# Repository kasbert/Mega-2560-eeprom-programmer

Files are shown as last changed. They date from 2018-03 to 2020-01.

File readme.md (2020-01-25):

# EEprom programmer with Mega 2560

Links:
http://danceswithferrets.org/geekblog/?page_id=903

http://danceswithferrets.org/geekblog/?p=496

Just upload sketch into Mega 2560 arduino.
Build and attach adapter (LED's + resistors are optional):

PCB Eagle+Gerber (Elecrow/Jlcpcb) are in pcb:

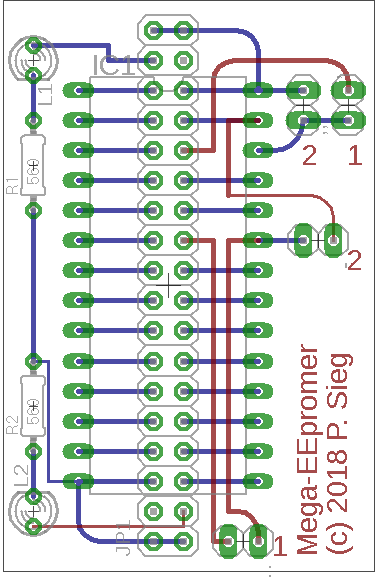
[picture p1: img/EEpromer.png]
PCB


2 Jumper at 1 are for 28C256 and 28C64.
2 Jumper at 2 are for 28C16.

PCB's arrived and they work as expected.

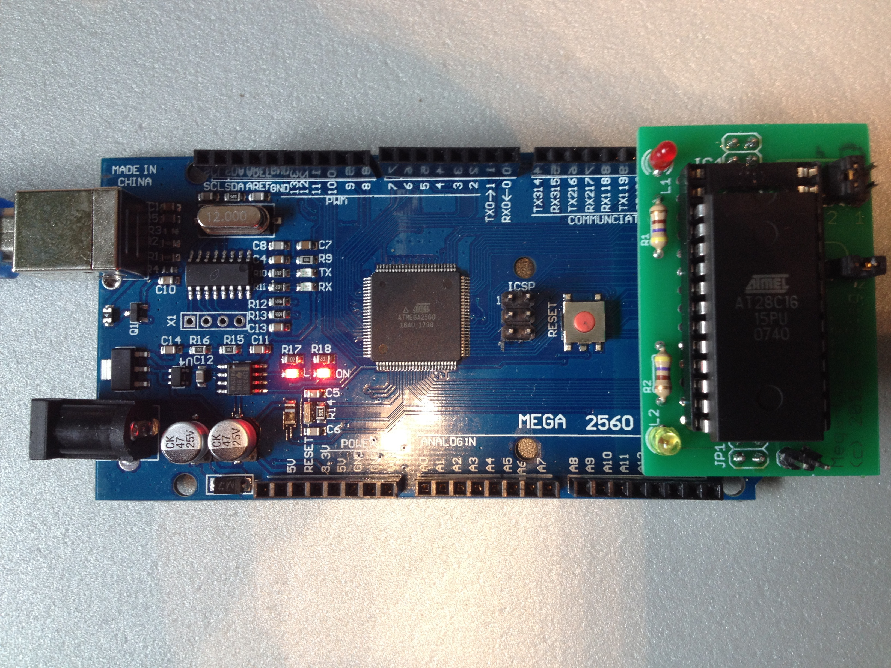
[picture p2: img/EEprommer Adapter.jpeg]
JCLPCB


See eeprom.ino and eeprommer.py for details

---
Hardware variant 2 uses Mega 2560 Pro Mini and the long side of pins.

Atmega 2560 Pins 31 - 4 are connected to EEPROM
```
 D4---A14 -+---+- VCC---5V
 D6---A12 -+ E +- /WE---D7
 D8----A7 -+ E +- A13---D9
D10----A6 -+ P +- A8----D11
D12----A5 -+ R +- A9 ---D13
D14----A4 -+ O +- A11---D15
D16----A3 -+ M +- /OE---D17
D18----A2 -+   +- A10---D19
D20----A1 -+   +- /CE---D21
D22----A0 -+   +- D7----D23
D24----D0 -+   +- D6----D25
D26----D1 -+   +- D5----D27
D28----D2 -+   +- D4----D29
GND---GND -+---+- D3----D31
```
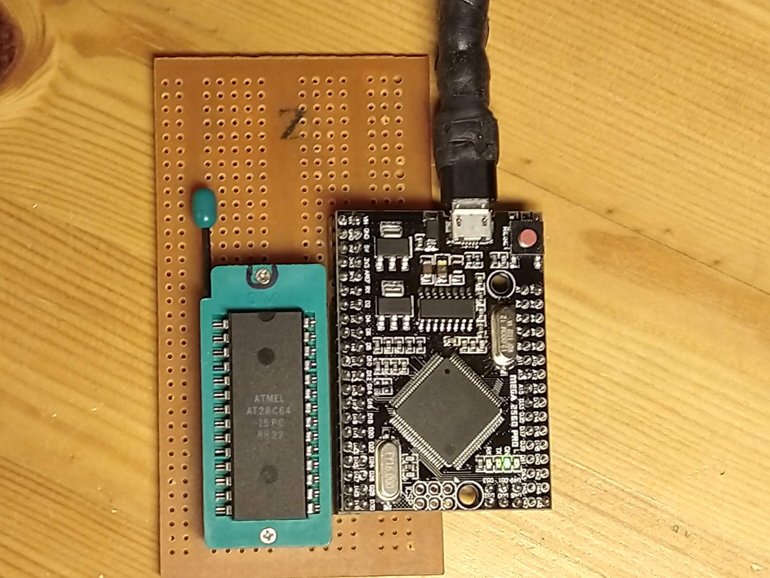
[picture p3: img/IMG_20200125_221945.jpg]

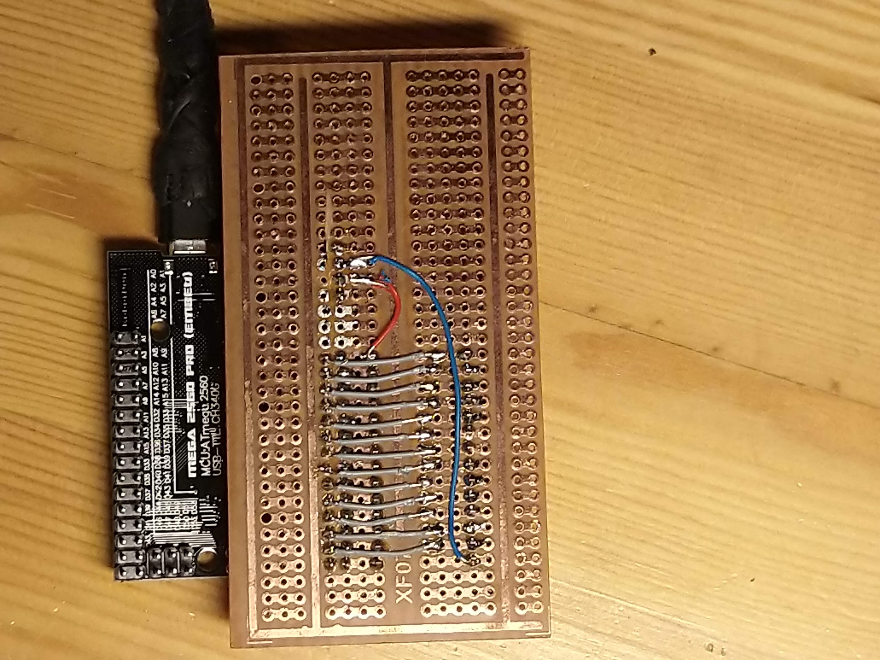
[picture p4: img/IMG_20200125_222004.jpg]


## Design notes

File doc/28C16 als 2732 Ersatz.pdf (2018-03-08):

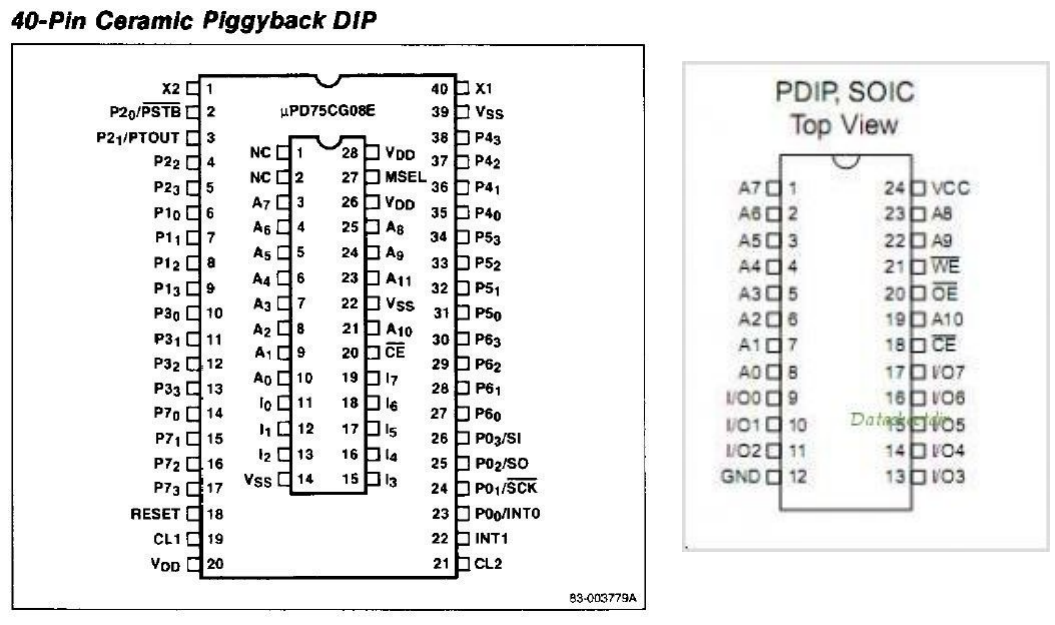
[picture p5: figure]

AT28C16 anstatt 2732 nehmen beim uPD75CG08

Pin 21-/WE aus der Fassung lassen (braucht nicht mit VCC/VDD=+5V verbunden werden). Der wäre sonst mit A11 verbunden, was wir nicht wollen.
/OE liegt an VSS=GND – das sollte so passen
Die anderen Pins passen übereinander

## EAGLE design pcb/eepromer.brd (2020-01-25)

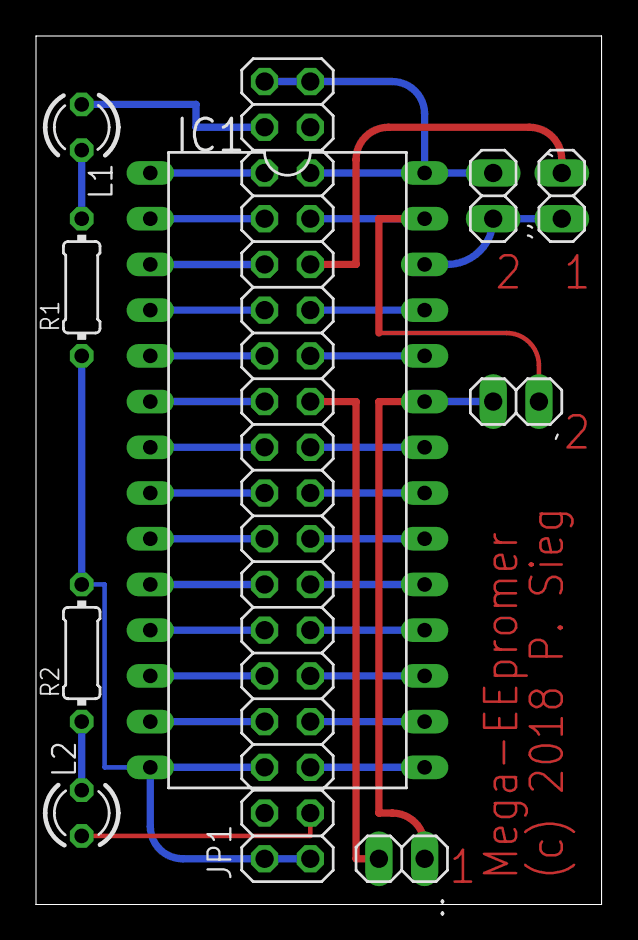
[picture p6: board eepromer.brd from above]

Board: 2 copper layers, 31.4 x 48.2 mm, 10 parts (0 on the bottom side), 34 nets.

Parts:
': 1X02
,: 1X02
,,: 1X02
:: 1X02
IC1: DIL28-6
JP1: 2X18
L1, L2: LED3MM
R1, R2: 560; 0204/7

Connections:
S$1: ,.1, IC1.28, JP1.31, JP1.36
S$2: IC1.14, JP1.1, JP1.6, R1.1, R2.2
S$3: JP1.3, L2.A
S$4: ,,.2, JP1.27
S$5: ,.2, ,,.1, IC1.26
S$6: L2.K, R2.1
S$7: '.1, IC1.27, JP1.29
S$8: IC1.25, JP1.25
S$9: IC1.24, JP1.23
S$10: IC1.22, JP1.19
S$11: IC1.21, JP1.17
S$12: IC1.20, JP1.15
S$13: IC1.19, JP1.13
S$14: IC1.18, JP1.11
S$15: IC1.17, JP1.9
S$16: IC1.16, JP1.7
S$17: IC1.15, JP1.5
S$18: IC1.13, JP1.8
S$19: IC1.12, JP1.10
S$20: IC1.11, JP1.12
S$21: IC1.10, JP1.14
S$22: IC1.9, JP1.16
S$23: IC1.8, JP1.18
S$24: IC1.7, JP1.20
S$25: IC1.6, JP1.22
S$26: IC1.5, JP1.24
S$27: IC1.4, JP1.26
S$28: IC1.3, JP1.28
S$29: IC1.2, JP1.30
S$30: IC1.1, JP1.32
S$31: :.2, JP1.21
S$32: '.2, :.1, IC1.23
S$33: L1.K, R1.2
S$34: JP1.34, L1.A

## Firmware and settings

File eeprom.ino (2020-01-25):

// EEPROM Programmer - code for an Arduino Mega 2560
//
// Written by K Adcock.
//       Jan 2016 - Initial release
//       Dec 2017 - Slide code tartups, to remove compiler errors for new Arduino IDE (1.8.5).
//   7th Dec 2017 - Updates from Dave Curran of Tynemouth Software, adding commands to enable/disable SDP.
//  10th Dec 2017 - Fixed one-byte EEPROM corruption (always byte 0) when unprotecting an EEPROM
//                  (doesn't matter if you write a ROM immediately after, but does matter if you use -unprotect in isolation)
//                - refactored code a bit (split loop() into different functions)
//                - properly looked at timings on the Atmel datasheet, and worked out that my delays
//                  during reads and writes were about 10,000 times too big!
//                  Reading and writing is now orders-of-magnitude quicker.
//  21st Feb 2018 - P. Sieg
//                  static const long int k_uTime_WriteDelay_uS = 500; // delay between byte writes - needed for at28c16
//                  delayMicroseconds(k_uTime_WritePulse_uS);
//  06th Oct 2018 - P. Sieg
//                - corrected SDP (un)protect adresses & k_uTime_WriteDelay_uS
//                - Set parameters -A=28C16; -B=28C64; -C=28C256
//  29th Jan 2019 - P. Sieg
//                - Introduced + and - to alter k_uTime_WritePulse_uS
//  25th Jan 2020 - J. Sonninen
//                - Add read polling after write
//
//
// Distributed under an acknowledgement licence, because I'm a shallow, attention-seeking tart. :)
//
// http://danceswithferrets.org/geekblog/?page_id=903
//
// This software presents a 9600-8N1 serial port.
//
// R[hex address]                         - reads 16 bytes of data from the EEPROM
// W[hex address]:[data in two-char hex]  - writes up to 16 bytes of data to the EEPROM
// P                                      - set write-protection bit (Atmels only, AFAIK)
// U                                      - clear write-protection bit (ditto)
// V                                      - prints the version string
// A                                      - set parameters for 28C16
// B                                      - set parameters for 28C64
// C                                      - set parameters for 28C256
// +                                      - k_uTime_WritePulse_uS + 50
// -                                      - k_uTime_WritePulse_uS - 25
//
// Any data read from the EEPROM will have a CRC checksum appended to it (separated by a comma).
// If a string of data is sent with an optional checksum, then this will be checked
// before anything is written.
//

#include <avr/pgmspace.h>

const char hex[] =
{
  '0', '1', '2', '3', '4', '5', '6', '7',
  '8', '9', 'a', 'b', 'c', 'd', 'e', 'f'
};

const char version_string[] = {"EEPROM Version=0.05-kasbert"};

#define HW_VARIANT 0 // Select 1 or 2

#if HW_VARIANT == 1
static const int kPin_Addr14  = 24;
static const int kPin_Addr12  = 26;
static const int kPin_Addr7   = 28;
static const int kPin_Addr6   = 30;
static const int kPin_Addr5   = 32;
static const int kPin_Addr4   = 34;
static const int kPin_Addr3   = 36;
static const int kPin_Addr2   = 38;
static const int kPin_Addr1   = 40;
static const int kPin_Addr0   = 42;
static const int kPin_Data0   = 44;
static const int kPin_Data1   = 46;
static const int kPin_Data2   = 48;
static const int kPin_nWE     = 27;
static const int kPin_Addr13  = 29;
static const int kPin_Addr8   = 31;
static const int kPin_Addr9   = 33;
static const int kPin_Addr11  = 35;
static const int kPin_nOE     = 37;
static const int kPin_Addr10  = 39;
static const int kPin_nCE     = 41;
static const int kPin_Data7   = 43;
static const int kPin_Data6   = 45;
static const int kPin_Data5   = 47;
static const int kPin_Data4   = 49;
static const int kPin_Data3   = 51;
static const int kPin_WaitingForInput  = 13;
static const int kPin_LED_Red = 22;
static const int kPin_LED_Grn = 53;
#elif HW_VARIANT == 2
static const int kPin_Addr14  = 4;
static const int kPin_Addr12  = 6;
static const int kPin_Addr7   = 8;
static const int kPin_Addr6   = 10;
static const int kPin_Addr5   = 12;
static const int kPin_Addr4   = 14;
static const int kPin_Addr3   = 16;
static const int kPin_Addr2   = 18;
static const int kPin_Addr1   = 20;
static const int kPin_Addr0   = 22;
static const int kPin_Data0   = 24;
static const int kPin_Data1   = 26;
static const int kPin_Data2   = 28;
static const int kPin_nWE     = 7;
static const int kPin_Addr13  = 9;
static const int kPin_Addr8   = 11;
static const int kPin_Addr9   = 13;
static const int kPin_Addr11  = 15;
static const int kPin_nOE     = 17;
static const int kPin_Addr10  = 19;
static const int kPin_nCE     = 21;
static const int kPin_Data7   = 23;
static const int kPin_Data6   = 25;
static const int kPin_Data5   = 27;
static const int kPin_Data4   = 29;
static const int kPin_Data3   = 31;
static const int kPin_WaitingForInput  = 48;
static const int kPin_LED_Red = 50;
static const int kPin_LED_Grn = 52;
#else
#error Select HW_VARIANT 1 or 2
#endif


byte g_cmd[80]; // strings received from the controller will go in here
static const int kMaxBufferSize = 16;
byte buffer[kMaxBufferSize];

static const long int k_uTime_WritePulse_uS = 1; 
static const long int k_uTime_ReadPulse_uS = 1;
             long int k_uTime_WriteDelay_uS = -1; // delay between byte writes - needed for at28c16
// (to be honest, both of the above are about ten times too big - but the Arduino won't reliably
// delay down at the nanosecond level, so this is the best we can do.)
// -1 enables polling of written value. At least 28C64 reads inverted value until the write has completed.
             long int SDPadr1=0x5555, SDPadr2=0x2AAA; // default 28C256
// the setup function runs once when you press reset or power the board
void setup()
{
  Serial.begin(9600);
//  Serial.println(version_string);
  
  pinMode(kPin_WaitingForInput, OUTPUT); digitalWrite(kPin_WaitingForInput, HIGH);
  pinMode(kPin_LED_Red, OUTPUT); digitalWrite(kPin_LED_Red, LOW);
  pinMode(kPin_LED_Grn, OUTPUT); digitalWrite(kPin_LED_Grn, LOW);

  // address lines are ALWAYS outputs
  pinMode(kPin_Addr0,  OUTPUT);
  pinMode(kPin_Addr1,  OUTPUT);
  pinMode(kPin_Addr2,  OUTPUT);
  pinMode(kPin_Addr3,  OUTPUT);
  pinMode(kPin_Addr4,  OUTPUT);
  pinMode(kPin_Addr5,  OUTPUT);
  pinMode(kPin_Addr6,  OUTPUT);
  pinMode(kPin_Addr7,  OUTPUT);
  pinMode(kPin_Addr8,  OUTPUT);
  pinMode(kPin_Addr9,  OUTPUT);
  pinMode(kPin_Addr10, OUTPUT);
  pinMode(kPin_Addr11, OUTPUT);
  pinMode(kPin_Addr12, OUTPUT);
  pinMode(kPin_Addr13, OUTPUT);
  pinMode(kPin_Addr14, OUTPUT);

  // control lines are ALWAYS outputs
  pinMode(kPin_nCE, OUTPUT); digitalWrite(kPin_nCE, LOW); // might as well keep the chip enabled ALL the time
  pinMode(kPin_nOE, OUTPUT); digitalWrite(kPin_nOE, HIGH);
  pinMode(kPin_nWE, OUTPUT); digitalWrite(kPin_nWE, HIGH); // not writing

  SetDataLinesAsInputs();
  SetAddress(0);
}

void loop()
{
  while (true)
  {
    digitalWrite(kPin_WaitingForInput, HIGH);
    ReadString();
    digitalWrite(kPin_WaitingForInput, LOW);
    
    switch (g_cmd[0])
    {
      case 'V': Serial.println(version_string); break;
      case 'P': SetSDPState(true); break;
      case 'U': SetSDPState(false); break;
      case 'R': ReadEEPROM(); break;
      case 'W': WriteEEPROM(); break;
      case 'A': k_uTime_WriteDelay_uS=100;  
                SDPadr1=-1; SDPadr2=-1; Serial.println("Set params for 28C16");break;
      case 'B': k_uTime_WriteDelay_uS=5;  
                SDPadr1=0x1555; SDPadr2=0x0AAA; Serial.println("Set params for 28C64");break;
      case 'C': k_uTime_WriteDelay_uS=5;  
                SDPadr1=0x5555; SDPadr2=0x2AAA; Serial.println("Set params for 28C256");break;
      case 'D': k_uTime_WriteDelay_uS=-1;  
                Serial.println("Poll read after write");break;
      case '+': k_uTime_WriteDelay_uS=k_uTime_WriteDelay_uS+50;  
                if (k_uTime_WriteDelay_uS > 500) k_uTime_WriteDelay_uS = 500; 
                Serial.print("k_uTime_WriteDelay_uS=");Serial.println(k_uTime_WriteDelay_uS,DEC); break;
      case '-': k_uTime_WriteDelay_uS=k_uTime_WriteDelay_uS-25; 
                if (k_uTime_WriteDelay_uS < 5) k_uTime_WriteDelay_uS = 5; 
                Serial.print("k_uTime_WriteDelay_uS=");Serial.println(k_uTime_WriteDelay_uS,DEC); break;
      case 0: break; // empty string. Don't mind ignoring this.
      default: Serial.println("ERR Unrecognised command"); break;
    }
  }
}

void ReadEEPROM() // R<address>  - read kMaxBufferSize bytes from EEPROM, beginning at <address> (in hex)
{
  if (g_cmd[1] == 0)
  {
    Serial.println("ERR");
    return;
  }

  // decode ASCII representation of address (in hex) into an actual value
  int addr = 0;
  int x = 1;
  while (x < 5 && g_cmd[x] != 0)
  {
    addr = addr << 4;
    addr |= HexToVal(g_cmd[x++]);
  }     

  digitalWrite(kPin_nWE, HIGH); // disables write
  SetDataLinesAsInputs();
  digitalWrite(kPin_nOE, LOW); // makes the EEPROM output the byte
  delayMicroseconds(1);
      
  ReadEEPROMIntoBuffer(addr, kMaxBufferSize);

  // now print the results, starting with the address as hex ...
  Serial.print(hex[ (addr & 0xF000) >> 12 ]);
  Serial.print(hex[ (addr & 0x0F00) >> 8  ]);
  Serial.print(hex[ (addr & 0x00F0) >> 4  ]);
  Serial.print(hex[ (addr & 0x000F)       ]);
  Serial.print(":");
  PrintBuffer(kMaxBufferSize);

  Serial.println("OK");

  digitalWrite(kPin_nOE, HIGH); // stops the EEPROM outputting the byte
}

void WriteEEPROM() // W<four byte hex address>:<data in hex, two characters per byte, max of 16 bytes per line>
{
  if (g_cmd[1] == 0)
  {
    Serial.println("ERR");
    return;
  }

  int addr = 0;
  int x = 1;
  while (g_cmd[x] != ':' && g_cmd[x] != 0)
  {
    addr = addr << 4;
    addr |= HexToVal(g_cmd[x]);
    ++x;
  }

  // g_cmd[x] should now be a :
  if (g_cmd[x] != ':')
  {
    Serial.println("ERR");
    return;
  }
  
  x++; // now points to beginning of data
  uint8_t iBufferUsed = 0;
  while (g_cmd[x] && g_cmd[x+1] && iBufferUsed < kMaxBufferSize && g_cmd[x] != ',')
  {
    uint8_t c = (HexToVal(g_cmd[x]) << 4) | HexToVal(g_cmd[x+1]);
    buffer[iBufferUsed++] = c;
    x += 2;
  }

  // if we're pointing to a comma, then the optional checksum has been provided!
  if (g_cmd[x] == ',' && g_cmd[x+1] && g_cmd[x+2])
  {
    byte checksum = (HexToVal(g_cmd[x+1]) << 4) | HexToVal(g_cmd[x+2]);

    byte our_checksum = CalcBufferChecksum(iBufferUsed);

    if (our_checksum != checksum)
    {
      // checksum fail!
      iBufferUsed = -1;
      Serial.print("ERR ");
      Serial.print(checksum, HEX);
      Serial.print(" ");
      Serial.print(our_checksum, HEX);
      Serial.println("");
      return;
    }
  }

  // buffer should now contains some data
  if (iBufferUsed > 0)
  {
    WriteBufferToEEPROM(addr, iBufferUsed);
  }

  if (iBufferUsed > -1)
  {
    Serial.println("OK");
  }
}

// Important note: the EEPROM needs to have data written to it immediately after sending the "unprotect" command, so that the buffer is flushed.
// So we read byte 0 from the EEPROM first, then use that as the dummy write afterwards.
// It wouldn't matter if this facility was used immediately before writing an EEPROM anyway ... but it DOES matter if you use this option
// in isolation (unprotecting the EEPROM but not changing it).

void SetSDPState(bool bWriteProtect)
{
  if (SDPadr1 < 0) {
    Serial.println("SDP feature not supported by chip");
    return;
  }
  digitalWrite(kPin_LED_Red, HIGH);

  digitalWrite(kPin_nWE, HIGH); // disables write
  digitalWrite(kPin_nOE, LOW); // makes the EEPROM output the byte
  SetDataLinesAsInputs();
  
  byte bytezero = ReadByteFrom(0);
  
  digitalWrite(kPin_nOE, HIGH); // stop EEPROM from outputting byte
  digitalWrite(kPin_nCE, HIGH);
  SetDataLinesAsOutputs();

  if (bWriteProtect)
  {
    WriteByteTo(SDPadr1, 0xAA);
    WriteByteTo(SDPadr2, 0x55);
    WriteByteTo(SDPadr1, 0xA0);
  }
  else
  {
    WriteByteTo(SDPadr1, 0xAA);
    WriteByteTo(SDPadr2, 0x55);
    WriteByteTo(SDPadr1, 0x80);
    WriteByteTo(SDPadr1, 0xAA);
    WriteByteTo(SDPadr2, 0x55);
    WriteByteTo(SDPadr1, 0x20);
  }
  
  WriteByteTo(0x0000, bytezero); // this "dummy" write is required so that the EEPROM will flush its buffer of commands.

  digitalWrite(kPin_nCE, LOW); // return to on by default for the rest of the code
  digitalWrite(kPin_LED_Red, LOW);

  Serial.print("OK SDP ");
  if (bWriteProtect)
  {
    Serial.println("enabled");
  }
  else
  {
    Serial.println("disabled");
  }
}

// ----------------------------------------------------------------------------------------

void ReadEEPROMIntoBuffer(int addr, int size)
{
  digitalWrite(kPin_LED_Grn, HIGH);
  digitalWrite(kPin_nWE, HIGH);
  SetDataLinesAsInputs();
  digitalWrite(kPin_nOE, LOW);
  
  for (int x = 0; x < size; ++x)
  {
    buffer[x] = ReadByteFrom(addr + x);
  }

  digitalWrite(kPin_nOE, HIGH);
  digitalWrite(kPin_LED_Grn, LOW);
}

void WriteBufferToEEPROM(int addr, int size)
{
  digitalWrite(kPin_LED_Red, HIGH);
  digitalWrite(kPin_nOE, HIGH); // stop EEPROM from outputting byte
  digitalWrite(kPin_nWE, HIGH); // disables write
  SetDataLinesAsOutputs();

  for (uint8_t x = 0; x < size; ++x)
  {
    WriteByteTo(addr + x, buffer[x]);
    if (k_uTime_WriteDelay_uS >= 0) {
      delayMicroseconds(k_uTime_WriteDelay_uS);
    } else {
      uint8_t i;
      SetDataLinesAsInputs();
      SetData(0); // disable pullups
      for (i = 0; i < 100; ++i) {
        digitalWrite(kPin_nCE, LOW);
        delayMicroseconds(k_uTime_ReadPulse_uS);
        byte b = ReadByteFrom(addr);
        digitalWrite(kPin_nCE, HIGH);
        if (buffer[x] == b) {
          break;
        }
        Serial.print("*");
      }
      SetDataLinesAsOutputs();
      if (i == 100) {
        Serial.println("ERR");
        return;
      }
    }
  }
  
  digitalWrite(kPin_LED_Red, LOW);
}

// ----------------------------------------------------------------------------------------

// this function assumes that data lines have already been set as INPUTS, and that
// nOE is set LOW.
byte ReadByteFrom(int addr)
{
  SetAddress(addr);
  digitalWrite(kPin_nCE, LOW);
  delayMicroseconds(k_uTime_ReadPulse_uS);
  byte b = ReadData();
  digitalWrite(kPin_nCE, HIGH);

  return b;
}

// this function assumes that data lines have already been set as OUTPUTS, and that
// nOE is set HIGH.
void WriteByteTo(int addr, byte b)
{
  SetAddress(addr);
  SetData(b);

  digitalWrite(kPin_nCE, LOW);
  digitalWrite(kPin_nWE, LOW); // enable write  
  delayMicroseconds(k_uTime_WritePulse_uS);
  
  digitalWrite(kPin_nWE, HIGH); // disable write
  digitalWrite(kPin_nCE, HIGH); 
}

// ----------------------------------------------------------------------------------------

void SetDataLinesAsInputs()
{
  pinMode(kPin_Data0, INPUT);
  pinMode(kPin_Data1, INPUT);
  pinMode(kPin_Data2, INPUT);
  pinMode(kPin_Data3, INPUT);
  pinMode(kPin_Data4, INPUT);
  pinMode(kPin_Data5, INPUT);
  pinMode(kPin_Data6, INPUT);
  pinMode(kPin_Data7, INPUT);
}

void SetDataLinesAsOutputs()
{
  pinMode(kPin_Data0, OUTPUT);
  pinMode(kPin_Data1, OUTPUT);
  pinMode(kPin_Data2, OUTPUT);
  pinMode(kPin_Data3, OUTPUT);
  pinMode(kPin_Data4, OUTPUT);
  pinMode(kPin_Data5, OUTPUT);
  pinMode(kPin_Data6, OUTPUT);
  pinMode(kPin_Data7, OUTPUT);
}

void SetAddress(int a)
{
  digitalWrite(kPin_Addr0,  (a&1)?HIGH:LOW    );
  digitalWrite(kPin_Addr1,  (a&2)?HIGH:LOW    );
  digitalWrite(kPin_Addr2,  (a&4)?HIGH:LOW    );
  digitalWrite(kPin_Addr3,  (a&8)?HIGH:LOW    );
  digitalWrite(kPin_Addr4,  (a&16)?HIGH:LOW   );
  digitalWrite(kPin_Addr5,  (a&32)?HIGH:LOW   );
  digitalWrite(kPin_Addr6,  (a&64)?HIGH:LOW   );
  digitalWrite(kPin_Addr7,  (a&128)?HIGH:LOW  );
  digitalWrite(kPin_Addr8,  (a&256)?HIGH:LOW  );
  digitalWrite(kPin_Addr9,  (a&512)?HIGH:LOW  );
  digitalWrite(kPin_Addr10, (a&1024)?HIGH:LOW );
  digitalWrite(kPin_Addr11, (a&2048)?HIGH:LOW );
  digitalWrite(kPin_Addr12, (a&4096)?HIGH:LOW );
  digitalWrite(kPin_Addr13, (a&8192)?HIGH:LOW );
  digitalWrite(kPin_Addr14, (a&16384)?HIGH:LOW);
}

// this function assumes that data lines have already been set as OUTPUTS.
void SetData(byte b)
{
  digitalWrite(kPin_Data0, (b&1)?HIGH:LOW  );
  digitalWrite(kPin_Data1, (b&2)?HIGH:LOW  );
  digitalWrite(kPin_Data2, (b&4)?HIGH:LOW  );
  digitalWrite(kPin_Data3, (b&8)?HIGH:LOW  );
  digitalWrite(kPin_Data4, (b&16)?HIGH:LOW );
  digitalWrite(kPin_Data5, (b&32)?HIGH:LOW );
  digitalWrite(kPin_Data6, (b&64)?HIGH:LOW );
  digitalWrite(kPin_Data7, (b&128)?HIGH:LOW);
}

// this function assumes that data lines have already been set as INPUTS.
byte ReadData()
{
  byte b = 0;

  if (digitalRead(kPin_Data0) == HIGH) b |= 1;
  if (digitalRead(kPin_Data1) == HIGH) b |= 2;
  if (digitalRead(kPin_Data2) == HIGH) b |= 4;
  if (digitalRead(kPin_Data3) == HIGH) b |= 8;
  if (digitalRead(kPin_Data4) == HIGH) b |= 16;
  if (digitalRead(kPin_Data5) == HIGH) b |= 32;
  if (digitalRead(kPin_Data6) == HIGH) b |= 64;
  if (digitalRead(kPin_Data7) == HIGH) b |= 128;

  return(b);
}

// ----------------------------------------------------------------------------------------

void PrintBuffer(int size)
{
  uint8_t chk = 0;

  for (uint8_t x = 0; x < size; ++x)
  {
    Serial.print(hex[ (buffer[x] & 0xF0) >> 4 ]);
    Serial.print(hex[ (buffer[x] & 0x0F)      ]);

    chk = chk ^ buffer[x];
  }

  Serial.print(",");
  Serial.print(hex[ (chk & 0xF0) >> 4 ]);
  Serial.print(hex[ (chk & 0x0F)      ]);
  Serial.println("");
}

void ReadString()
{
  int i = 0;
  byte c;

  g_cmd[0] = 0;
  do
  {
    if (Serial.available())
    {
      c = Serial.read();
      if (c > 31)
      {
        g_cmd[i++] = c;
        g_cmd[i] = 0;
      }
    }
  } 
  while (c != 10);
}

uint8_t CalcBufferChecksum(uint8_t size)
{
  uint8_t chk = 0;

  for (uint8_t x = 0; x < size; ++x)
  {
    chk = chk ^  buffer[x];
  }

  return(chk);
}

// converts one character of a HEX value into its absolute value (nibble)
byte HexToVal(byte b)
{
  if (b >= '0' && b <= '9') return(b - '0');
  if (b >= 'A' && b <= 'F') return((b - 'A') + 10);
  if (b >= 'a' && b <= 'f') return((b - 'a') + 10);
  return(0);
}

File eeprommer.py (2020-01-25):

#!/usr/bin/env python2.7
# Uses the Arduino firmware given on http://danceswithferrets.org/geekblog/?p=496
#
# -b size (in decimal)              - blank eeprom with 0xff
# -r start end (in decimal)         - read eeprom to terminal
# -s file.bin (programming)         - program eeprom with file.bin
# -v file.bin (verify content)      - program eeprom with file.bin
# -S file.bin ('smart' programming) - smart programming with file.bin
# -U                                - disable write protection
# -P                                - enable write protection
# -A                                - set parameters for 28C16
# -B                                - set parameters for 28C64
# -C                                - set parameters for 28C256
#
# Normally takes 196 seconds to program a 28C64, and 32 seconds to read.
# --
# Chris Baird,, <cjb@brushtail.apana.org.au> threw
# this together during an all-nighter on 2017-Oct-19.
# minor alterations/add. functions by Peter Sieg (peter.sieg1@gmx.de) in 2018:
# -b
# This version: 2018-Jan-02.

import sys
import serial
import time
import argparse

RECSIZE = 16
NL = chr(10)

parser = argparse.ArgumentParser()
parser.add_argument("-V", "--version", help="version", action="store_true")
parser.add_argument("-d", "--debug", help="debug", action="store_true")
parser.add_argument("-p", "--port", help="device, default /dev/ttyUSB0", default='/dev/ttyUSB0')
parser.add_argument("-b", type=int, help="blank eeprom with 0xff")
parser.add_argument("-r", type=int, nargs=2, help="read eeprom to terminal or file")
parser.add_argument("-v", type=argparse.FileType("rb"), help="verify programming with file.bin")
parser.add_argument("-s", type=argparse.FileType("rb"), help="program eeprom with file.bin")
parser.add_argument("-S", type=argparse.FileType("rb"), help="smart programming with file.bin")
parser.add_argument("-U", help="disable write protection", action="store_true")
parser.add_argument("-P", help="enable write protection", action="store_true")
parser.add_argument("-A", help="set parameters for 28C16", action="store_true")
parser.add_argument("-B", help="set parameters for 28C64", action="store_true")
parser.add_argument("-C", help="set parameters for 28C256", action="store_true")
parser.add_argument("-D", help="poll read after write", action="store_true")
parser.add_argument('args', nargs=argparse.REMAINDER)

opts = parser.parse_args()

ser = serial.Serial(opts.port, 9600, timeout=0.1)
time.sleep(1.0)

dumpstart = -1
dumpend = -1
romsize = 2048

def calcwriteline(a, l):
    ck = 0
    s = "W" + ("%04x" % a) + ":"
    for c in l:
        s = s + ("%02x" % ord(c))
        ck = ck ^ ord(c)
    s = s + "ffffffffffffffffffffffffffffffff"
    s = s[:38]
    if (len(l) & 1):
        ck = ck ^ 255
    ck = ck & 255
    s = s + "," + ("%02x" % ck)
    return s.upper()


def cmd(s, w=False):
    if opts.debug:
        print '>', repr(s)
    ser.write(s + NL)
    if w:
        s = waitokay()
    else:
        s = ser.readline()
        if opts.debug:
            print '<', repr(s)
    return s

def waitokay():
    bad = 0
    while True:
        s = ser.readline()
        if opts.debug:
            print '<', repr(s)
        if s == "OK\r\n":
            return s
        else:
            bad = bad + 1
        if bad > 50:
            sys.exit("eh")

def parseRecord(l):
    rom = [None]*RECSIZE
    for p in range(RECSIZE):
        i = 5 + (p*2)
        c = int(l[i:i+2], 16)
        rom[p] = c
    return rom

def recordToText(a, rom):
    romt = "%04x:" % a
    for p in range(RECSIZE):
        romt = romt + str(" %02x" % rom[p])
    return romt

def recordCheksum(rom):
    ck = 0
    for p in range(len(rom)):
        ck = ck ^ rom[p]
    return ck

def binToRecord(r):
    rec = [None]*len(r)
    for i in range(len(r)):
        rec[i] = ord(r[i])
    return rec



if opts.version:
    print cmd('V')
    sys.exit()

#s = sys.argv[0]

if opts.A:
    cmd('A')
if opts.B:
    cmd('B')
if opts.C:
    cmd('C')
if opts.D:
    cmd('D')
if opts.U:
    cmd('U')
if opts.P:
    cmd('P')

if opts.b:
    a = 0
    romsize = int(opts.b)
    while True:
        s = "W" + ("%04x" % a) + ":ffffffffffffffffffffffffffffffff"
        cmd(s, True)
        a = a + RECSIZE
        if a >= romsize:
            break

if opts.r:
    dumpstart = opts.r[0]
    dumpend = opts.r[1]
    if len(opts.args):
        f = open(opts.args[0], 'wb')
    else:
        f = False
    if dumpstart > -1:
        while (dumpstart <= dumpend):
            l = cmd("R%04x" % dumpstart)
            rom = parseRecord(l)
            waitokay()
            if f:
                for p in range(0,len(rom)):
                    f.write(chr(rom[p]))
                f.flush()
                if not opts.debug:
                    print l.upper().strip(), "\r",
                sys.stdout.flush()
            else:
                if not opts.debug:
                    print l.upper().strip()
            ck = recordCheksum(rom)
            val = int(l[38:40],16)
            if (val != ck):
                sys.exit("chksum " + val + "!=" + ck)
            dumpstart = dumpstart + RECSIZE
        if f:
            print

if opts.s:
    f = opts.s
    #f = open(opts.s, 'rb')
    a = 0
    while True:
        l = f.read(RECSIZE)
        if len(l) == 0:
            break
        s = calcwriteline(a, l)
        if opts.debug != True:
            print s, "\r",
            sys.stdout.flush()
        cmd(s, True);
        if len(l) != RECSIZE:
            break
        a = a + RECSIZE
    f.close()
    print

if opts.v:
    f = opts.v
    #f = open(sys.argv[1], 'rb')
    a = 0
    badcount = 0
    while True:
        r = f.read(RECSIZE)
        if len(r) == 0:
            break
        okay = 1
        rec = binToRecord(r)

        l = cmd("R%04x" % a)
        waitokay()
        rom = parseRecord(l)
        print "ROM ", recordToText(a, rom), "\r",
        sys.stdout.flush()

        filet = "FILE %04x:" % a
        for i in range(len(r)):
            if rom[i] != rec[i]:
                okay = 0
                badcount = badcount + 1
                filet = filet + "*%02x" % rec[i]
            else:
                filet = filet + " %02x" % rec[i]

        if okay == 0:
            print
            print filet,
            print "MISMATCH!!"
            #sys.exit()

        if len(r) != RECSIZE:
            break
        else:
            a = a + RECSIZE

    print
    print badcount, "errors!"
    f.close()
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

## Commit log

2018-10-06 Add files via upload
    eeprommer.py - included command -P = enable software write protection + -U disable software write protection
    eeprom.ino - corrected SDP adresses
    [eeprom.ino, eeprommer.py]
2020-01-25 Move files around
    [eepromer.GBL, eepromer.GBO, eepromer.GBP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]

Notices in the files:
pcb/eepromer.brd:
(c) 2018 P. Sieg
